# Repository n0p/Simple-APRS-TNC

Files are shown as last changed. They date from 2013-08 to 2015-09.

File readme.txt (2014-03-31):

Simple inexpensive APRS TNC/beacon based on wb8wga's one

Update: It works! :D
http://imgur.com/mMHwAuk
http://imgur.com/1EDHPSL

Original work I adapted: http://www.enide.net/webcms/index.php?page=wb8wga-tnc

This device works as a stand alone configurable APRS beacon/digipeater and also as a serial to APRS terminal. Go to wb8wga's website to find more about it.

I scaled everything into SMD to make it as small as possible, removed the MAX232, as I intend to use this on embedded TTL devices and also I removed the connectors and left it as pin rows, also to embed it / save space.

3x05Ball.zip is the original TNC firmware, on which the wb8wga one is based, it should be compatible and make this board work as a standard APRS TNC.
I upload it here as is a bit hard to find, but I claim no ownership over it.

Disclaimer: 
This is my first EAGLE circuit, so be gentle with me xD

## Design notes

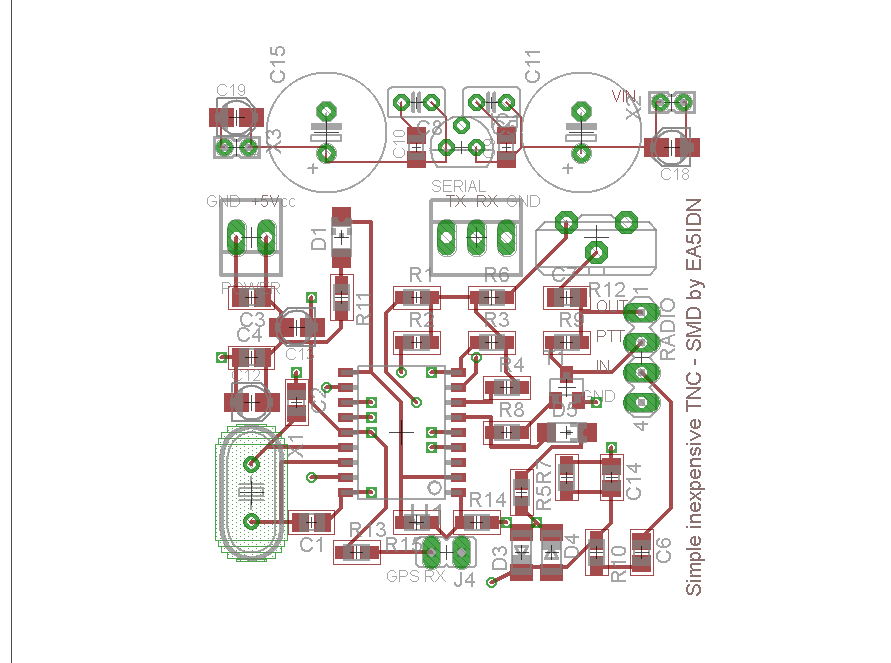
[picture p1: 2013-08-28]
top.png

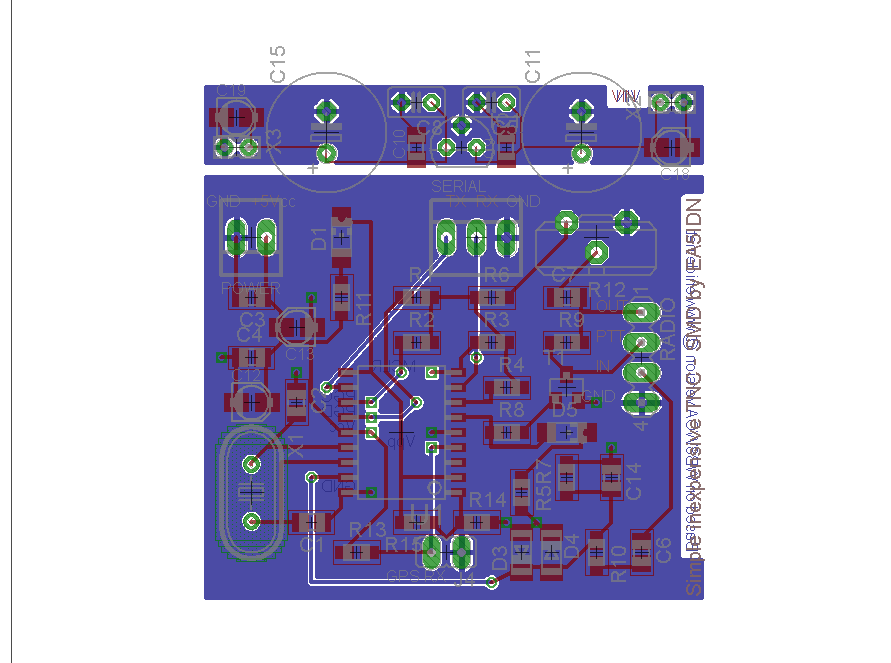
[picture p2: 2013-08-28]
circuit.png

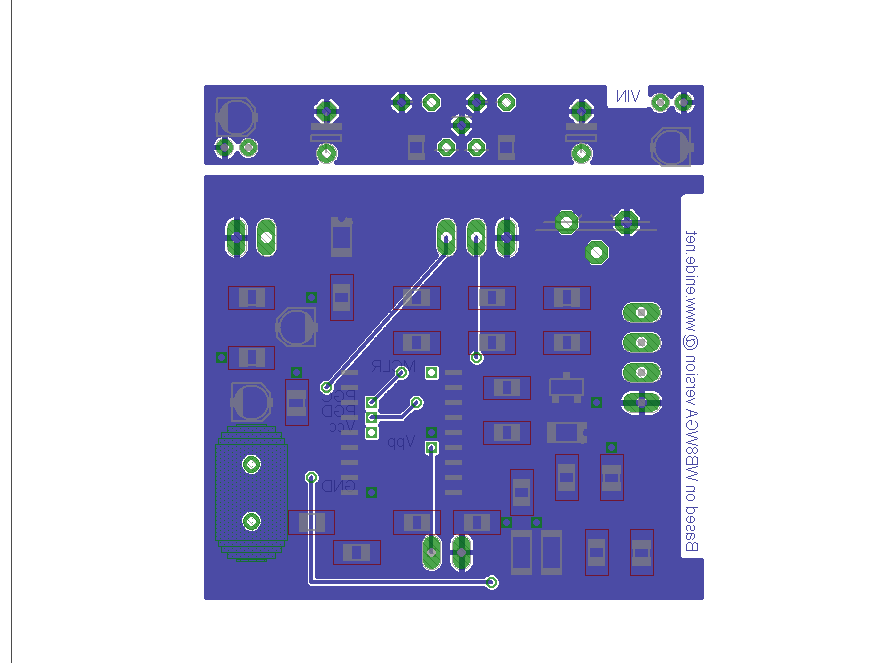
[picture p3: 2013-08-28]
bottom.png

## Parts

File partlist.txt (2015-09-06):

Partlist

Exported from InexpensiveTNC-v4-mod.sch at 9/5/15 3:22 AM

EAGLE Version 7.4.0 Copyright (c) 1988-2015 CadSoft

Assembly variant: 

Part     Value          Device               Package      Library        Sheet

C1       22p            C-EUC0805            C0805        rcl            1
C2       22p            C-EUC0805            C0805        rcl            1
C3       100n           C-EUC0805            C0805        rcl            1
C4       100n           C-EUC0805            C0805        rcl            1
C5                      C-EU025-025X050      C025-025X050 rcl            1
C6       100n           C-EUC0805            C0805        rcl            1
C7       100n           C-EUC0805            C0805        rcl            1
C8                      C-EU025-025X050      C025-025X050 rcl            1
C9                      C-EUC0805K           C0805K       rcl            1
C10                     C-EUC0805K           C0805K       rcl            1
C11                     CPOL-EUE3.5-10       E3,5-10      rcl            1
C12      220u/25V       CPOL-EUA             PANASONIC_A  rcl            1
C13      100u/10V       CPOL-EUA             PANASONIC_A  rcl            1
C14      1n             C-EUC0805            C0805        rcl            1
C15                     CPOL-EUE3.5-10       E3,5-10      rcl            1
C18      220u/25V       CPOL-EUA             PANASONIC_A  rcl            1
C19      220u/25V       CPOL-EUA             PANASONIC_A  rcl            1
D1       green          LEDCHIPLED_1206      CHIPLED_1206 led            1
D3       1n4148         DIODE-MINIMELF       MINIMELF     diode          1
D4       1n4148         DIODE-MINIMELF       MINIMELF     diode          1
D5       red            LEDCHIPLED_1206      CHIPLED_1206 led            1
IC1      78L05Z         78L05Z               TO92         linear         1
J4       GPS            JP1E                 JP1          jumper         1
POWER    22-23-2021     22-23-2021           22-23-2021   con-molex      1
R1       1K             R-EU_R0805W          R0805W       rcl            1
R2       2K             R-EU_R0805W          R0805W       rcl            1
R3       3K9            R-EU_R0805W          R0805W       rcl            1
R4       8K2            R-EU_R0805W          R0805W       rcl            1
R5       1K             R-EU_R0805W          R0805W       rcl            1
R6       100K           R-EU_R0805W          R0805W       rcl            1
R7       10k            R-EU_R0805W          R0805W       rcl            1
R8       1K             R-EU_R0805W          R0805W       rcl            1
R9       2K2            R-EU_R0805W          R0805W       rcl            1
R10      470            R-EU_R0805W          R0805W       rcl            1
R11      1K             R-EU_R0805W          R0805W       rcl            1
R12      10K            POTENTIOMETER_PT-10S PT-10S       rcl            1
R13      10K            R-EU_R0805W          R0805W       rcl            1
R14      470            R-EU_R0805W          R0805W       rcl            1
R15      100k           R-EU_R0805W          R0805W       rcl            1
RADIO                   MA04-1               MA04-1       con-lstb       1
SERIAL   22-23-2031     22-23-2031           22-23-2031   con-molex      1
T1       BC846BSMD      BC846BSMD            SOT23        transistor-npn 1
U1       PIC16F88       PIC16F83SO           SO-18W       microchip      1
X1       20MHz          CRYSTALHC49U70       HC49U70      crystal        1
X2       332-02         332-02               332-02       con-garry      1
X3       332-02         332-02               332-02       con-garry      1

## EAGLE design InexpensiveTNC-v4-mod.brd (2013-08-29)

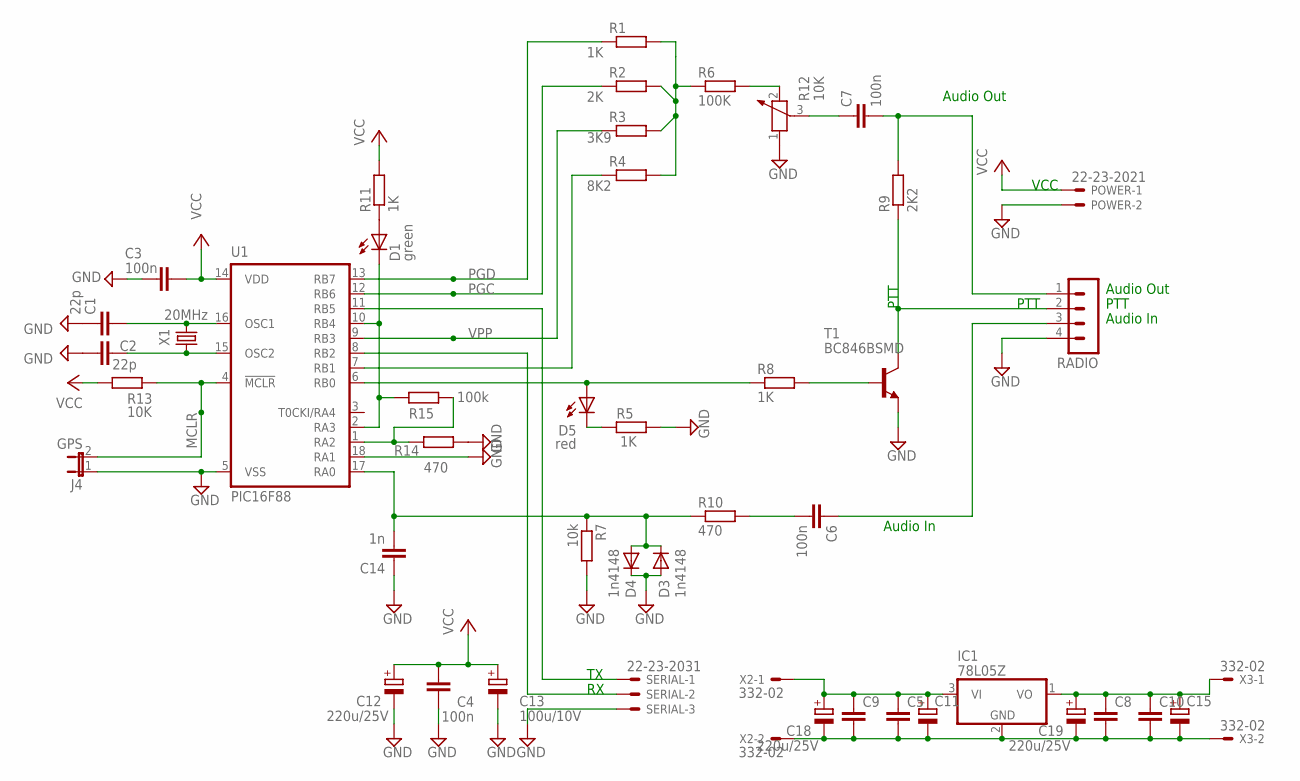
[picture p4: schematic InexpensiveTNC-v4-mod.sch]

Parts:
C1, C2: 22p; C0805
C3, C4, C6, C7: 100n; C0805
C5, C8: C-EU025-025X050; C025-025X050
C9, C10: C-EUC0805K; C0805K
C11, C15: CPOL-EUE3.5-10; E3,5-10
C12, C18, C19: 220u/25V; PANASONIC_A
C13: 100u/10V; PANASONIC_A
C14: 1n; C0805
D1: green; CHIPLED_1206
D3, D4: 1n4148; MINIMELF
D5: red; CHIPLED_1206
IC1: 78L05Z; TO92
J4: GPS; JP1
POWER: 22-23-2021
R1, R5, R8, R11: 1K; R0805W
R2: 2K; R0805W
R3: 3K9; R0805W
R4: 8K2; R0805W
R6: 100K; R0805W
R7: 10k; R0805W
R9: 2K2; R0805W
R10, R14: 470; R0805W
R12: 10K; PT-10S
R13: 10K; R0805W
R15: 100k; R0805W
RADIO: MA04-1
SERIAL: 22-23-2031
T1: BC846BSMD; SOT23
U1: PIC16F88; SO-18W; MPN PIC16F83-04/SO
X1: 20MHz; HC49U70
X2, X3: 332-02

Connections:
GND: C1.1, C2.1, C3.2, C4.1, C12.-, C13.-, C14.1, D3.A, D4.C, J4.1, POWER.2, R5.2, R7.2, R12.1, R14.2, RADIO.4, SERIAL.3, T1.2 (E), U1.5 (VSS), U1.18 (RA1)
MCLR: J4.2, R13.2, U1.4 (!MCLR)
unnamed: C1.2, U1.16 (OSC1), X1.2
unnamed: C2.2, U1.15 (OSC2), X1.1
unnamed: D1.A, R11.1
unnamed: R4.1, U1.7 (RB1)
unnamed: D1.C, R15.2, U1.2 (RA3), U1.10 (RB4)
unnamed: R8.2, T1.1 (B)
unnamed: R1.2, R2.2, R3.2, R4.2, R6.1
unnamed: R6.2, R12.2
unnamed: C7.1, R12.3
unnamed: D5.A, R8.1, U1.6 (RB0)
unnamed: D5.C, R5.1
unnamed: R9.1, RADIO.2, T1.3 (C)
unnamed: C7.2, R9.2, RADIO.1
unnamed: C14.2, D3.C, D4.A, R7.1, R10.1, U1.17 (RA0)
unnamed: C6.2, R10.2
unnamed: R14.1, R15.1, U1.1 (RA2)
unnamed: C6.1, RADIO.3
unnamed: SERIAL.1, U1.11 (RB5)
unnamed: SERIAL.2, U1.8 (RB2)
PGC: R2.1, U1.12 (RB6)
PGD: R1.1, U1.13 (RB7)
VCC: C3.1, C4.2, C12.+, C13.+, POWER.1, R11.2, R13.1, U1.14 (VDD)
VPP: R3.1, U1.9 (RB3)
VREG-GND: C5.2, C8.2, C9.2, C10.2, C11.-, C15.-, C18.-, C19.-, IC1.2 (GND), X2.2, X3.2
VREG-VIN: C5.1, C9.1, C11.+, C18.+, IC1.3 (VI), X2.1
VREG-VOUT: C8.1, C10.1, C15.+, C19.+, IC1.1 (VO), X3.1

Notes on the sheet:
Audio Out
PTT
Audio In
VCC

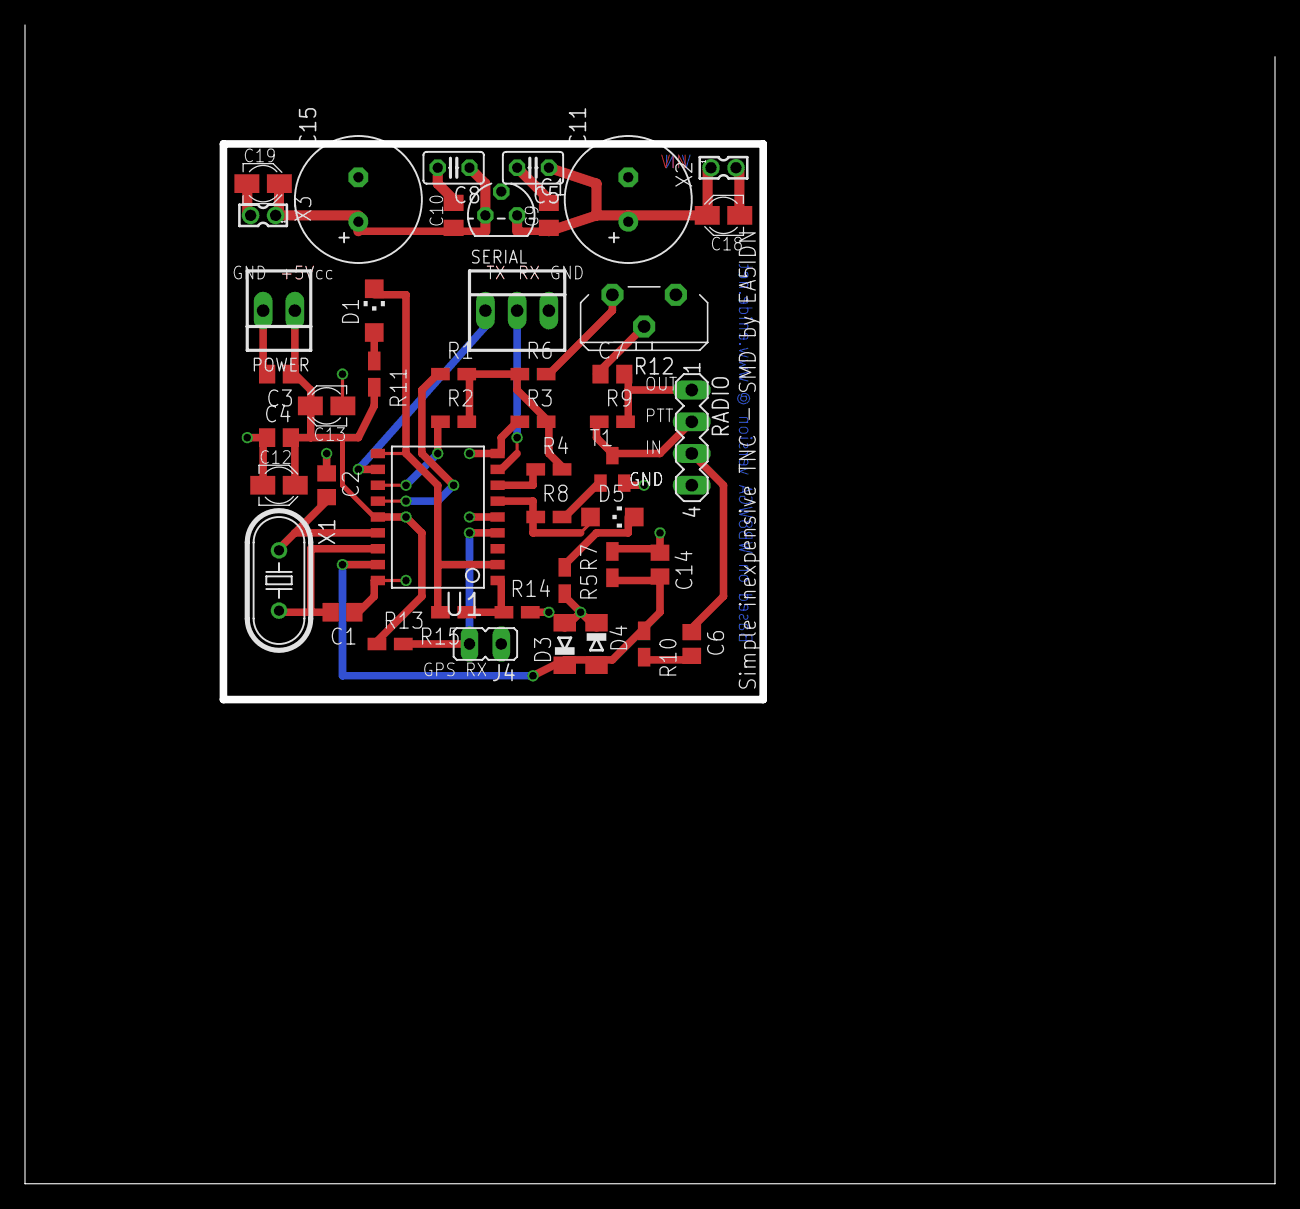
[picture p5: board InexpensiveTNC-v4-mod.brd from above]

Board: 2 copper layers, 43.2 x 44.5 mm, 46 parts (0 on the bottom side), 28 nets.
